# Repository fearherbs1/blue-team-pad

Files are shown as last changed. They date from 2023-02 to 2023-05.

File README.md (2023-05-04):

# blue-team-pad
An open source macropad for the cyber security analyst.

View the documentation for the Blue Team Pad by visiting: https://fearherbs1.github.io/blue-team-pad-docs/

Below is the demo unit that was shown at Champlain's 2023 ITS Capstone Showcase 
blue_team_pad

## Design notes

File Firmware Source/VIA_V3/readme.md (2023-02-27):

# Blue Team Pad

blue_team_pad

An open source macropad for the cyber security analyst.

The Blue Team Pad is a RP2040 based 4x5 macropad with two rotary encoders and OLED display.

It was specifically designed with the maximum possible space for macros supported by QMK. This allows the analyst to store various triage & remediation commands for quick access.

* Keyboard Maintainer: [Thomas Autiello Jr](https://github.com/fearherbs1)
* Hardware Supported: Custom RP2040 Based PCB
* Hardware Availability: https://github.com/fearherbs1/blue-team-pad 

Make example for this keyboard (after setting up your build environment):

    make fearherbs1/blue_team_pad:default

Flashing example for this keyboard:

    make fearherbs1/blue_team_pad:default:flash

See the [build environment setup](https://docs.qmk.fm/#/getting_started_build_tools) and the [make instructions](https://docs.qmk.fm/#/getting_started_make_guide) for more information. Brand new to QMK? Start with our [Complete Newbs Guide](https://docs.qmk.fm/#/newbs).

## Bootloader

Enter the bootloader in 2 ways:

* **Bootmagic reset**: Hold down the upper left encoder and plug in the keyboard
* **Physical reset button**: Briefly short the two "BOOT" pads on the back side of the pcb

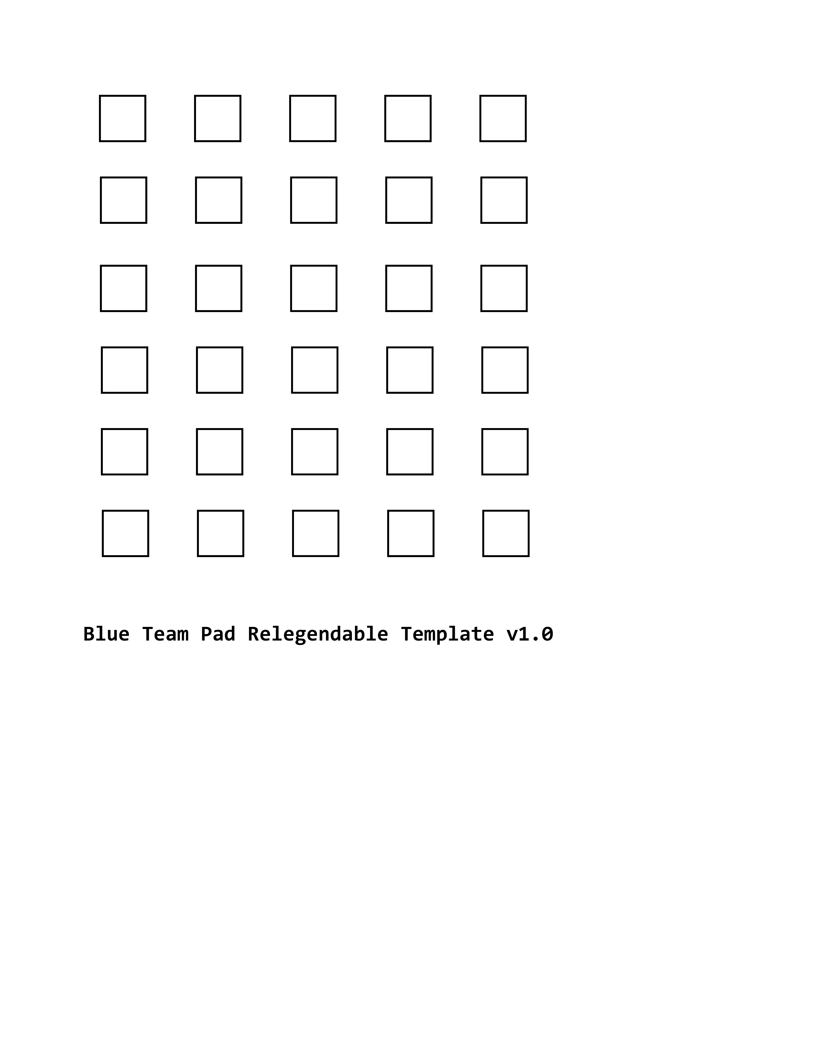
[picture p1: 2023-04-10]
Relegendable Template/BTP relegendable Template V1.png

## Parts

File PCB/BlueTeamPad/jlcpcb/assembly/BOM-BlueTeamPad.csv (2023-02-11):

Comment | Designator | Footprint | LCSC
1k | R5,R6 | R_0402_1005Metric | C11702
100nF | C11,C12,C13,C14,C15,C16,C17,C5,C7,C8 | C_0402_1005Metric | C1525
10uF | C9 | C_0402_1005Metric | C15525
22pF | C3,C4 | C_0402_1005Metric | C1555
USB_C | J1 | USB_C_Receptacle_HRO_TYPE-C-31-M-12 | C165948
RP2040 | U1 | RP2040-QFN-56 | C2040
27R | R1,R2 | R_0603_1608Metric | C25190
10k | R7 | R_0402_1005Metric | C25744
5.1k | R3,R4 | R_0402_1005Metric | C25905
1uF | C1,C10,C2,C6 | C_0402_1005Metric | C52923
XC6206 | U4 | SOT-23 | C5446
500mA | F1 | Fuse_1206_3216Metric | C70076
D_Small | D1,D10,D11,D12,D13,D14,D15,D16,D17,D18,D19,D2,D20,D21,D22,D3,D4,D5,D6,D7,D8,D9 | D_SOD-123 | C81598
SRV05-4 | U2 | SOT-23-6-routable | C85364
12MHz | Y1 | Crystal_SMD_3225-4Pin_3.2x2.5mm | C9002
W25Q128JVS | U3 | SOIC-8_5.23x5.23mm_P1.27mm | C97521
MountingHole_Pad | H2 | MountingHole_2.2mm_M2_Pad
OLED | OL1 | OLED_v2
MountingHole_Pad | H1 | MountingHole_2.2mm_M2_Pad
RotaryEncoder_Switch | SW3 | ROT_Alps_EC11E-Switch
MountingHole_Pad | H3 | MountingHole_2.2mm_M2_Pad
MountingHole_Pad | H4 | MountingHole_2.2mm_M2_Pad
RotaryEncoder_Switch | SW2 | ROT_Alps_EC11E-Switch
MX_SW_HS | SW20 | SW_MX_HS_1u
MX_SW_HS | SW5 | SW_MX_HS_1u
Boot | SW1 | PinSocket_1x02_P2.54mm_Vertical
MX_SW_HS | SW6 | SW_MX_HS_1u
MX_SW_HS | SW21 | SW_MX_HS_1u
MX_SW_HS | SW22 | SW_MX_HS_1u
MX_SW_HS | SW13 | SW_MX_HS_1u
MX_SW_HS | SW18 | SW_MX_HS_1u
MX_SW_HS | SW16 | SW_MX_HS_1u
MX_SW_HS | SW11 | SW_MX_HS_1u
MX_SW_HS | SW12 | SW_MX_HS_1u
MX_SW_HS | SW9 | SW_MX_HS_1u
MX_SW_HS | SW10 | SW_MX_HS_1u
MX_SW_HS | SW7 | SW_MX_HS_1u
MX_SW_HS | SW15 | SW_MX_HS_1u
MX_SW_HS | SW4 | SW_MX_HS_1u
MX_SW_HS | SW8 | SW_MX_HS_1u
MX_SW_HS | SW23 | SW_MX_HS_1u
MX_SW_HS | SW19 | SW_MX_HS_1u
MX_SW_HS | SW14 | SW_MX_HS_1u
MX_SW_HS | SW17 | SW_MX_HS_1u

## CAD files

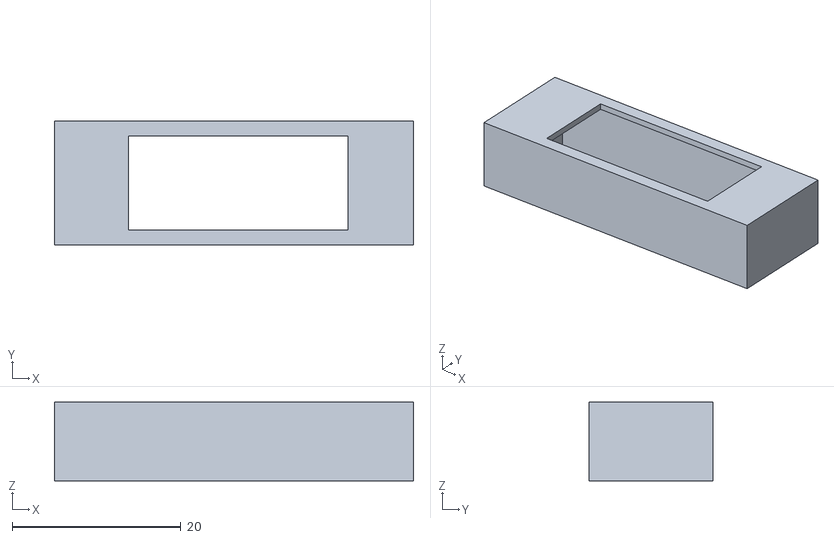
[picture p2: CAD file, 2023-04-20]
Case/STLs/oled_cover_oled_socket.stl
42.5 x 14.6 x 9.30

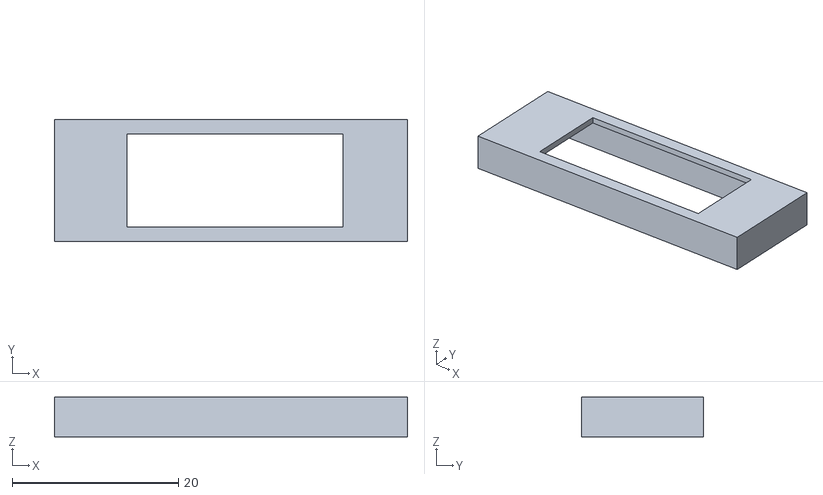
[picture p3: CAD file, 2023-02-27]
Case/STLs/oled cover.stl
42.5 x 14.6 x 4.80

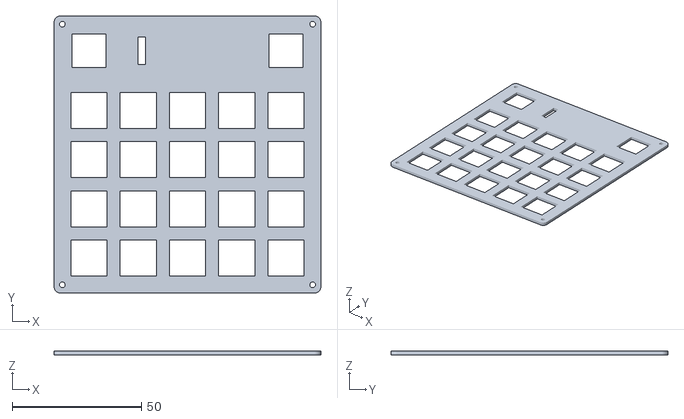
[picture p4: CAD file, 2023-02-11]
Case/STLs/plate.stl
103.2 x 107.2 x 1.60

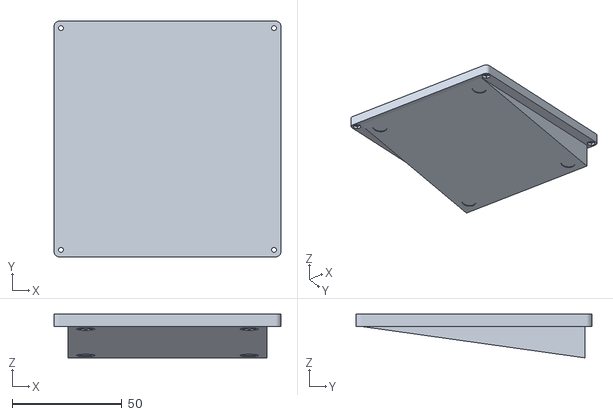
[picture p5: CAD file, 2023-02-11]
Case/STLs/bottom piece.stl
103.2 x 107.2 x 19.9

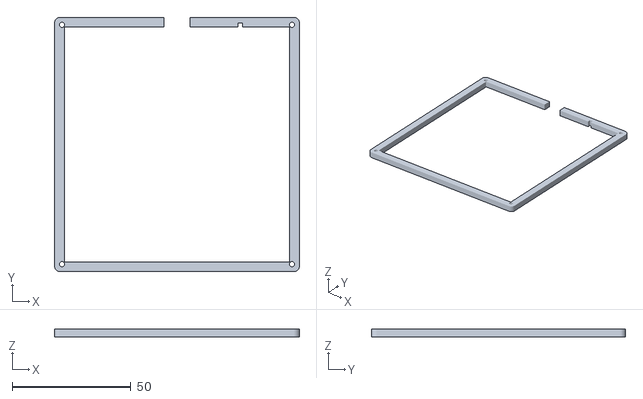
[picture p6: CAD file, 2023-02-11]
Case/STLs/mid peice_usb.stl
103.2 x 107.2 x 3.40

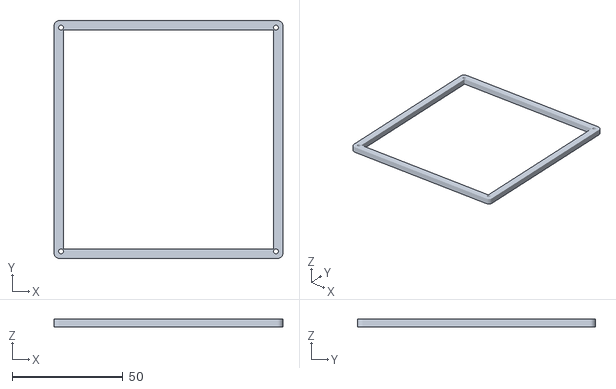
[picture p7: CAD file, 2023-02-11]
Case/STLs/mid peice_plate.stl
103.2 x 107.2 x 3.40

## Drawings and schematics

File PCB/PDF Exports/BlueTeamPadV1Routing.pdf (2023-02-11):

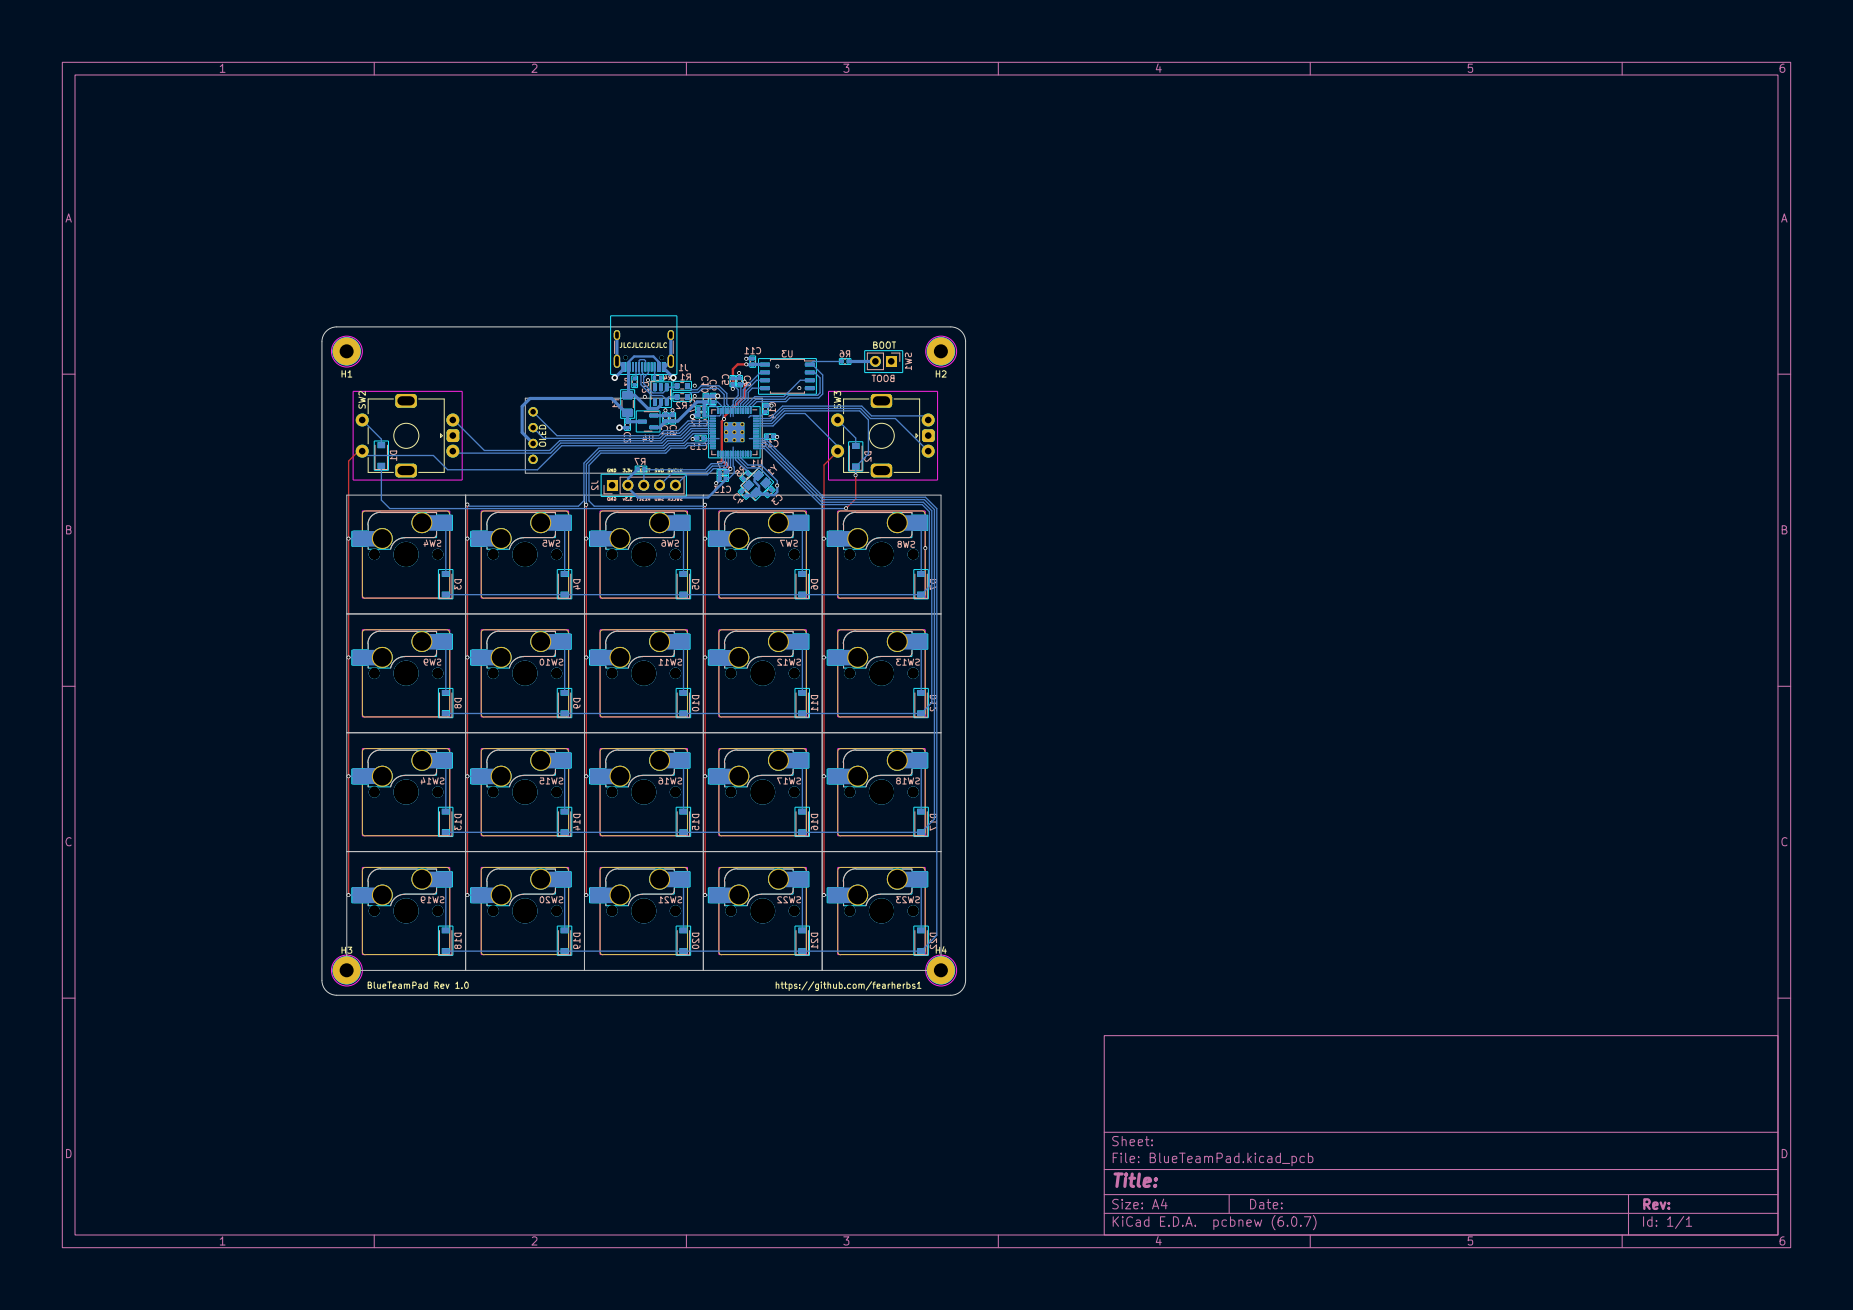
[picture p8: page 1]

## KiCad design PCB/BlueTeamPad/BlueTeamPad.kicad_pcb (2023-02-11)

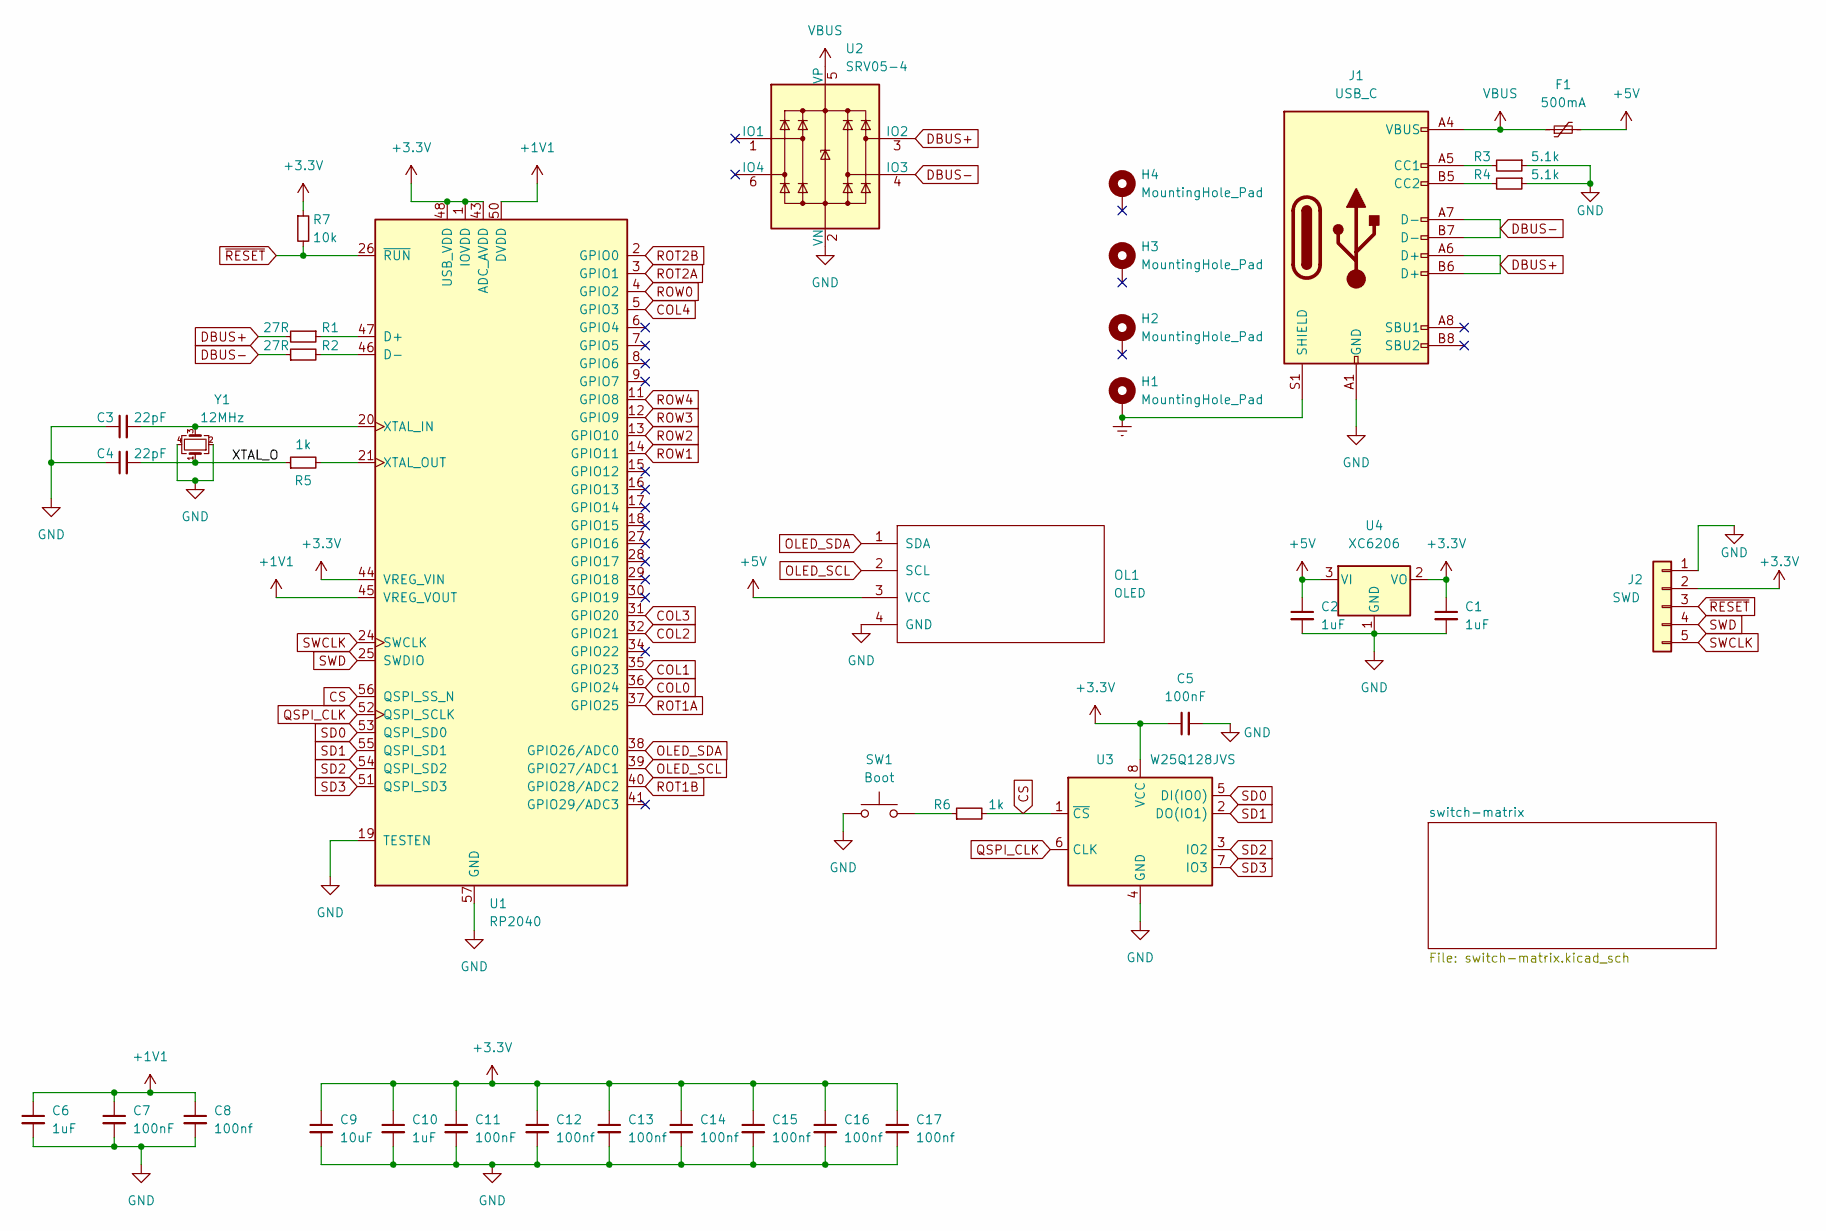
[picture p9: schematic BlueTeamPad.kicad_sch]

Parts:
C1, C2, C10: 1uF; C_0402_1005Metric; LCSC C52923
C3, C4: 22pF; C_0402_1005Metric; LCSC C1555
C5, C7, C11: 100nF; C_0402_1005Metric; LCSC C1525
C6: 1uF; C_0402_1005Metric
C8, C12, C13, C14, C15, C16, C17: 100nf; C_0402_1005Metric; LCSC C1525
C9: 10uF; C_0402_1005Metric; LCSC C15525
F1: 500mA; Fuse_1206_3216Metric; LCSC C70076
H1, H2, H3, H4: MountingHole_Pad; MountingHole_2.2mm_M2_Pad
J1: USB_C; USB_C_Receptacle_HRO_TYPE-C-31-M-12
J2: SWD; PinSocket_1x05_P2.54mm_Vertical
OL1: OLED; OLED_v2
R1, R2: 27R; R_0603_1608Metric; LCSC C25190
R3, R4: 5.1k; R_0402_1005Metric; LCSC C25905
R5, R6: 1k; R_0402_1005Metric; LCSC C11702
R7: 10k; R_0402_1005Metric; LCSC C25744
SW1: Boot; PinSocket_1x02_P2.54mm_Vertical
U1: RP2040; RP2040-QFN-56
U2: SRV05-4; SOT-23-6-routable; LCSC C85364
U3: W25Q128JVS; SOIC-8_5.23x5.23mm_P1.27mm; LCSC C97521
U4: XC6206; SOT-23; LCSC C5446
Y1: 12MHz; Crystal_SMD_3225-4Pin_3.2x2.5mm; LCSC C9002

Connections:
+1V1: C6.1, C7.1, C8.1, U1.23 (DVDD), U1.45 (VREG_VOUT), U1.50 (DVDD)
+3.3V: C1.1, C5.1, C9.1, C10.1, C11.1, C12.1, C13.1, C14.1, C15.1, C16.1, C17.1, J2.2, R7.1, U1.1 (IOVDD), U1.10 (IOVDD), U1.22 (IOVDD), U1.33 (IOVDD), U1.42 (IOVDD), U1.43 (ADC_AVDD), U1.44 (VREG_VIN), U1.48 (USB_VDD), U1.49 (IOVDD), U3.8 (VCC), U4.2 (VO)
+5V: C2.1, F1.2, OL1.3 (VCC), U4.3 (VI)
/XTAL_O: C4.2, R5.1, Y1.1
COL0: U1.36 (GPIO24); also elsewhere on the board
COL1: U1.35 (GPIO23); also elsewhere on the board
COL2: U1.32 (GPIO21); also elsewhere on the board
COL3: U1.31 (GPIO20); also elsewhere on the board
COL4: U1.5 (GPIO3); also elsewhere on the board
CS: R6.2, U1.56 (QSPI_SS_N), U3.1 (~CS)
DBUS+: J1.A6 (D+), J1.B6 (D+), R1.2, U2.3 (IO2)
DBUS-: J1.A7 (D-), J1.B7 (D-), R2.1, U2.4 (IO3)
Earth: H1.1, J1.S1 (SHIELD)
GND: C1.2, C2.2, C3.1, C4.1, C5.2, C6.2, C7.2, C8.2, C9.2, C10.2, C11.2, C12.2, C13.2, C14.2, C15.2, C16.2, C17.2, J1.A1 (GND), J1.A12 (GND), J1.B1 (GND), J1.B12 (GND), J2.1, OL1.4 (GND), R3.1, R4.1, SW1.1, U1.19 (TESTEN), U1.57 (GND), U2.2 (VN), U3.4 (GND), U4.1 (GND), Y1.2, Y1.4; also elsewhere on the board
unnamed: C3.2, U1.20 (XTAL_IN), Y1.3
unnamed: J1.A5 (CC1), R3.2
unnamed: J1.B5 (CC2), R4.2
unnamed: R1.1, U1.47 (D+)
unnamed: R2.2, U1.46 (D-)
unnamed: R5.2, U1.21 (XTAL_OUT)
unnamed: R6.1, SW1.2
OLED_SCL: OL1.2 (SCL), U1.39 (GPIO27/ADC1)
OLED_SDA: OL1.1 (SDA), U1.38 (GPIO26/ADC0)
QSPI_CLK: U1.52 (QSPI_SCLK), U3.6 (CLK)
ROT1A: U1.37 (GPIO25); also elsewhere on the board
ROT1B: U1.40 (GPIO28/ADC2); also elsewhere on the board
ROT2A: U1.3 (GPIO1); also elsewhere on the board
ROT2B: U1.2 (GPIO0); also elsewhere on the board
ROW0: U1.4 (GPIO2); also elsewhere on the board
ROW1: U1.14 (GPIO11); also elsewhere on the board
ROW2: U1.13 (GPIO10); also elsewhere on the board
ROW3: U1.12 (GPIO9); also elsewhere on the board
ROW4: U1.11 (GPIO8); also elsewhere on the board
SD0: U1.53 (QSPI_SD0), U3.5 (DI(IO0))
SD1: U1.55 (QSPI_SD1), U3.2 (DO(IO1))
SD2: U1.54 (QSPI_SD2), U3.3 (IO2)
SD3: U1.51 (QSPI_SD3), U3.7 (IO3)
SWCLK: J2.5, U1.24 (SWCLK)
SWD: J2.4, U1.25 (SWDIO)
VBUS: F1.1, J1.A4 (VBUS), J1.A9 (VBUS), J1.B4 (VBUS), J1.B9 (VBUS), U2.5 (VP)
~RESET: J2.3, R7.2, U1.26 (~RUN)

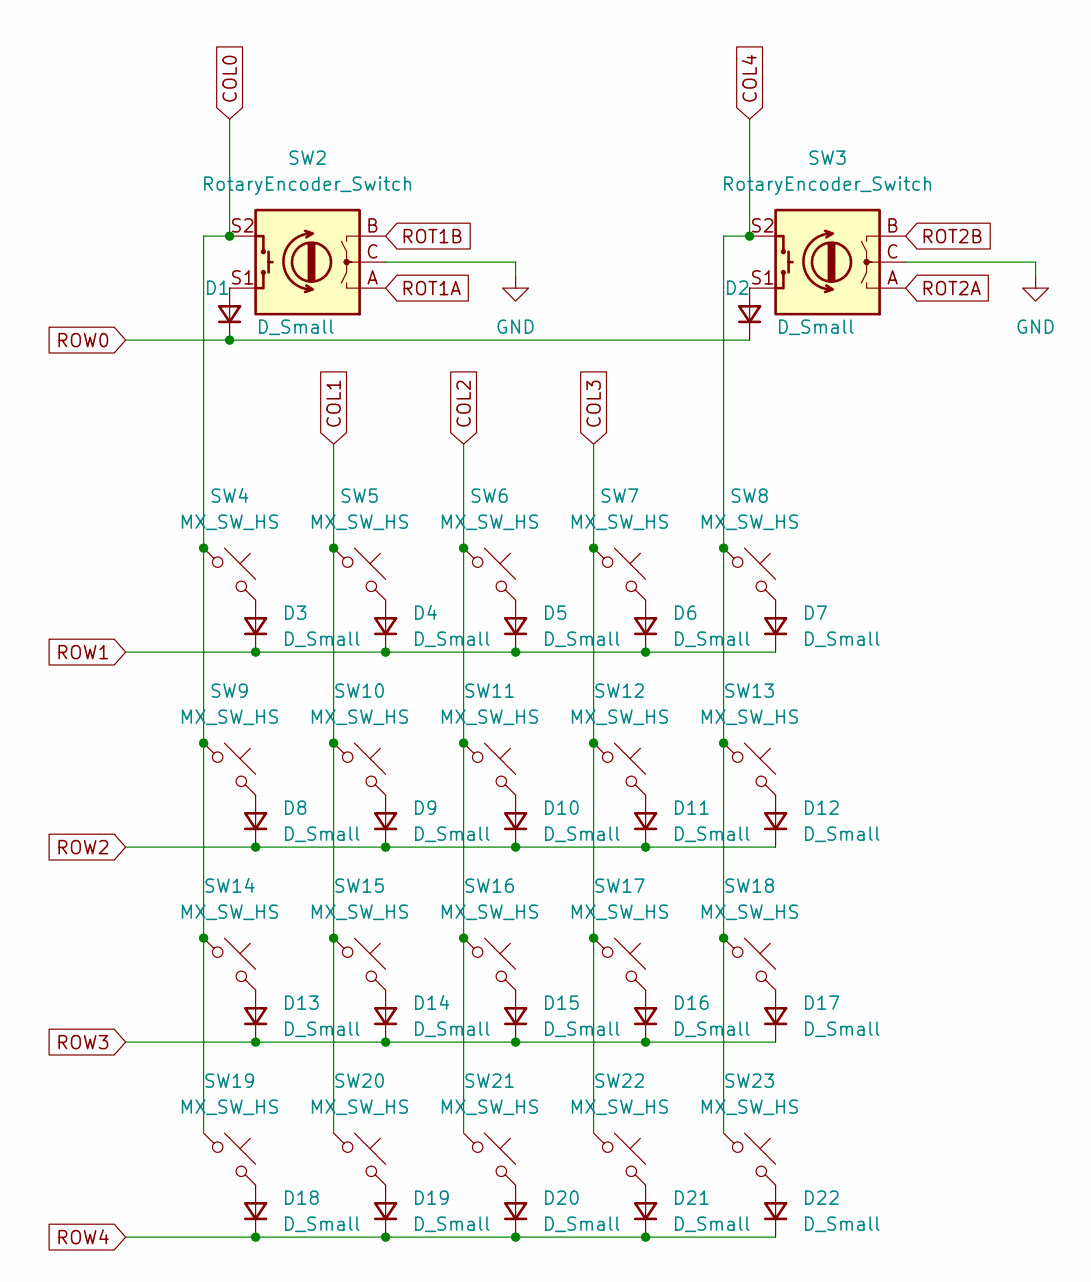
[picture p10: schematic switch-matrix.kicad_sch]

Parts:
D1, D2, D3, D4, D5, D6, D7, D8, D9, D10, D11, D12, D13, D14, D15, D16, D17, D18, D19, D20, D21, D22: D_Small; D_SOD-123; LCSC C81598
SW2, SW3: RotaryEncoder_Switch; ROT_Alps_EC11E-Switch
SW4, SW5, SW6, SW7, SW8, SW9, SW10, SW11, SW12, SW13, SW14, SW15, SW16, SW17, SW18, SW19, SW20, SW21, SW22, SW23: MX_SW_HS; SW_MX_HS_1u

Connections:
COL0: SW2.S2, SW4.1, SW9.1, SW14.1, SW19.1; also elsewhere on the board
COL1: SW5.1, SW10.1, SW15.1, SW20.1; also elsewhere on the board
COL2: SW6.1, SW11.1, SW16.1, SW21.1; also elsewhere on the board
COL3: SW7.1, SW12.1, SW17.1, SW22.1; also elsewhere on the board
COL4: SW3.S2, SW8.1, SW13.1, SW18.1, SW23.1; also elsewhere on the board
GND: SW2.C, SW3.C; also elsewhere on the board
unnamed: D1.2 (A), SW2.S1
unnamed: D2.2 (A), SW3.S1
unnamed: D3.2 (A), SW4.2
unnamed: D4.2 (A), SW5.2
unnamed: D5.2 (A), SW6.2
unnamed: D6.2 (A), SW7.2
unnamed: D7.2 (A), SW8.2
unnamed: D8.2 (A), SW9.2
unnamed: D9.2 (A), SW10.2
unnamed: D10.2 (A), SW11.2
unnamed: D11.2 (A), SW12.2
unnamed: D12.2 (A), SW13.2
unnamed: D13.2 (A), SW14.2
unnamed: D14.2 (A), SW15.2
unnamed: D15.2 (A), SW16.2
unnamed: D16.2 (A), SW17.2
unnamed: D17.2 (A), SW18.2
unnamed: D18.2 (A), SW19.2
unnamed: D19.2 (A), SW20.2
unnamed: D20.2 (A), SW21.2
unnamed: D21.2 (A), SW22.2
unnamed: D22.2 (A), SW23.2
ROT1A: SW2.A; also elsewhere on the board
ROT1B: SW2.B; also elsewhere on the board
ROT2A: SW3.A; also elsewhere on the board
ROT2B: SW3.B; also elsewhere on the board
ROW0: D1.1 (K), D2.1 (K); also elsewhere on the board
ROW1: D3.1 (K), D4.1 (K), D5.1 (K), D6.1 (K), D7.1 (K); also elsewhere on the board
ROW2: D8.1 (K), D9.1 (K), D10.1 (K), D11.1 (K), D12.1 (K); also elsewhere on the board
ROW3: D13.1 (K), D14.1 (K), D15.1 (K), D16.1 (K), D17.1 (K); also elsewhere on the board
ROW4: D18.1 (K), D19.1 (K), D20.1 (K), D21.1 (K), D22.1 (K); also elsewhere on the board

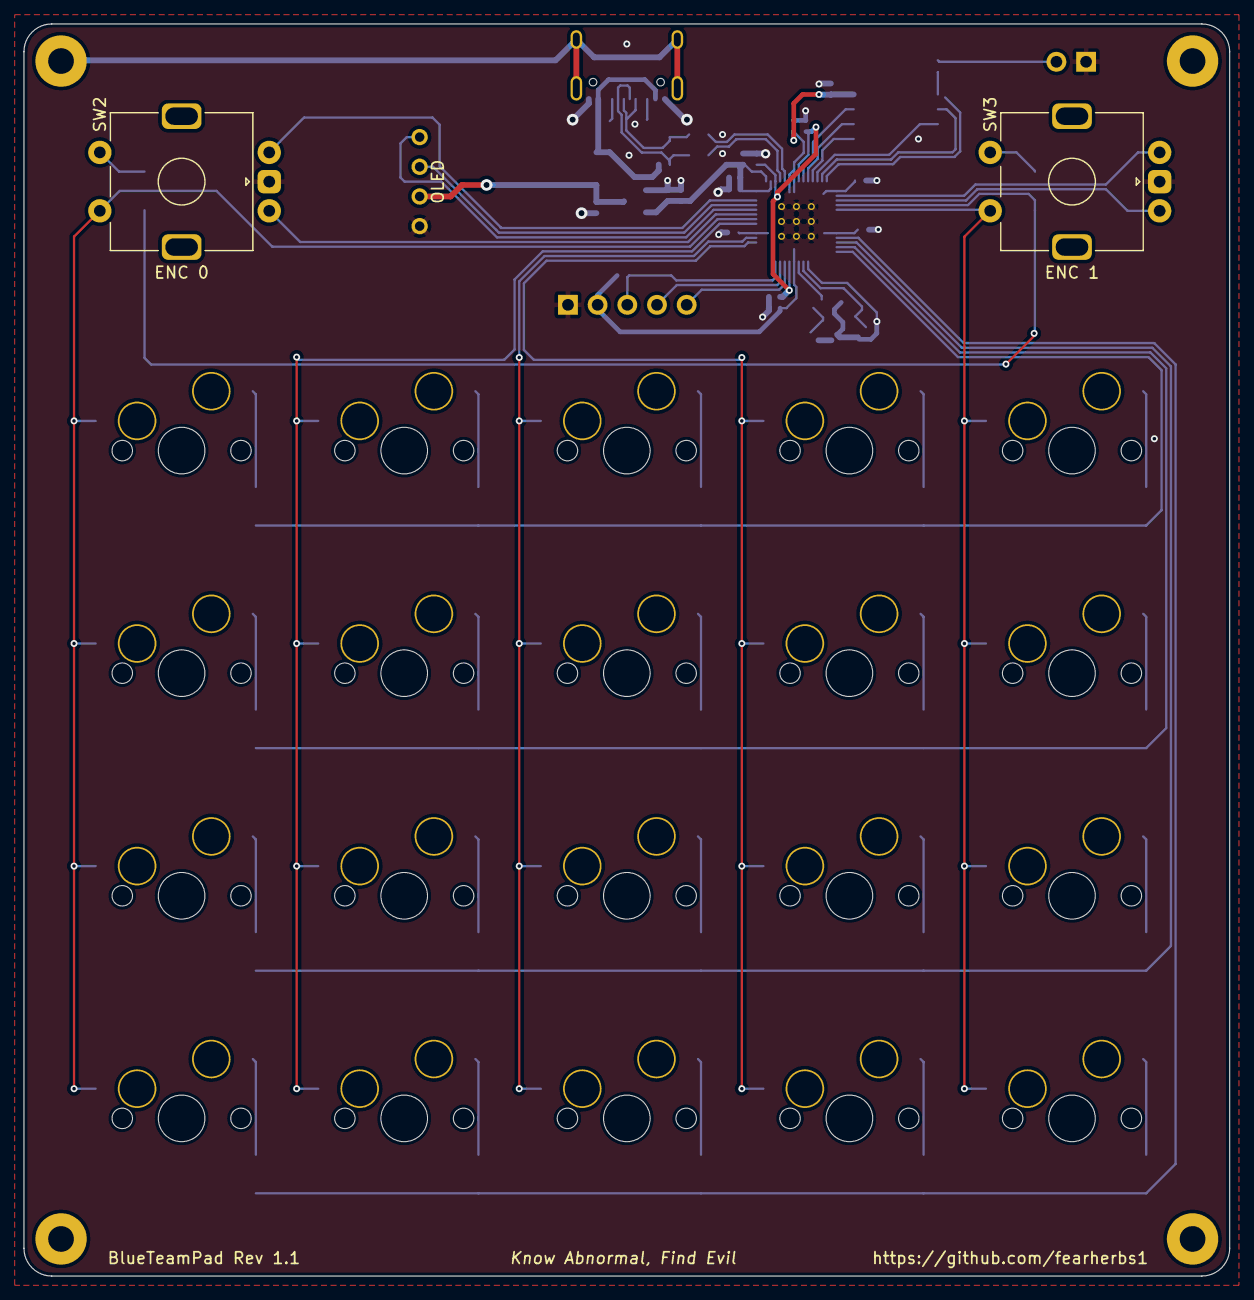
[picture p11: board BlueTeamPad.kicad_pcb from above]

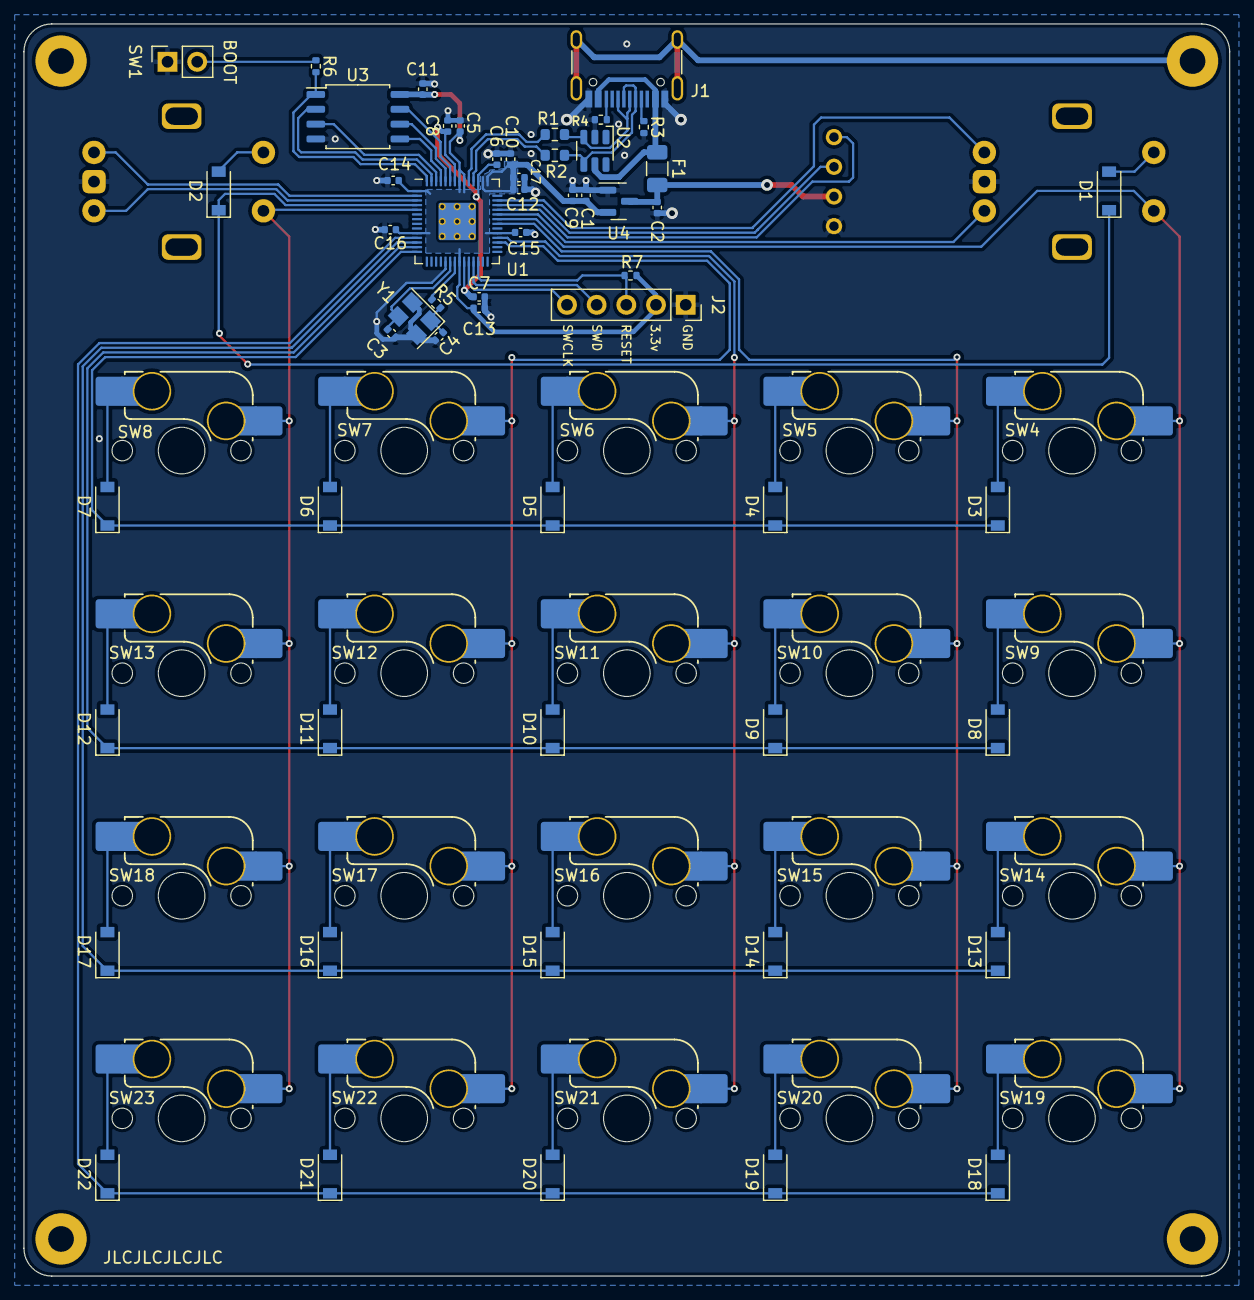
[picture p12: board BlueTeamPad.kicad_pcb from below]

Board: 2 copper layers, 103.2 x 107.2 mm, 82 parts (75 on the bottom side), 63 nets.

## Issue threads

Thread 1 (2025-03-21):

PolySprint

Wyvest, 2025-03-21:
Hi,

Sorry for the unrelated issue but I am unsure where else to contact you.

I am trying to "leave the fork network" and turn PolySprint into a standalone repo. However, I cannot as there are currently 3 child forks, including yours. Could you temporarily delete the repo and let me know when you do, so I can do this?

Thanks in advance

fearherbs1, 2025-03-22:
Hey @Wyvest, no worries, I went ahead and detached my PolySprint fork from the main PolySprint Repo, so it should not prevent you from "leaving the fork network" on your end.

Closed 2025-03-22.

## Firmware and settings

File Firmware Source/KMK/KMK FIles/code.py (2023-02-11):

print("Starting")

import board

from kmk.kmk_keyboard import KMKKeyboard
from kmk.consts import UnicodeMode
from kmk.keys import KC
from kmk.scanners import DiodeOrientation
from kmk.modules.layers import Layers
from kmk.modules.encoder import EncoderHandler
from kmk.extensions.media_keys import MediaKeys
from kmk.handlers.sequences import send_string

keyboard = KMKKeyboard()
layers = Layers()
encoder_handler = EncoderHandler()
keyboard.modules = [layers, encoder_handler]

encoder_handler.pins = ((board.GP25, board.GP28, None, False), (board.GP1, board.GP0, None, False),)
keyboard.col_pins = (board.GP24, board.GP23, board.GP21, board.GP20, board.GP3)
keyboard.row_pins = (board.GP2, board.GP11, board.GP10, board.GP9, board.GP8)
keyboard.diode_orientation = DiodeOrientation.COL2ROW

keyboard.extensions.append(MediaKeys())

encoder_handler.map = ( ((KC.AUDIO_VOL_UP, KC.AUDIO_VOL_DOWN, KC.NO),( KC.MEDIA_NEXT_TRACK, KC.MEDIA_PREV_TRACK,KC.NO),),
                        ((KC.AUDIO_VOL_UP, KC.AUDIO_VOL_DOWN, KC.NO),( KC.MEDIA_NEXT_TRACK, KC.MEDIA_PREV_TRACK,KC.NO),),
                        ((KC.AUDIO_VOL_UP, KC.AUDIO_VOL_DOWN, KC.NO),( KC.MEDIA_NEXT_TRACK, KC.MEDIA_PREV_TRACK,KC.NO),),
                        )

keyboard.debug_enabled = False

M1 = send_string("gci \"C:\\Users\\*\\AppData\\Roaming\\Microsoft\\Windows\\Start Menu\\Programs\\Startup\\*\"")

keyboard.keymap = [
    [
    KC.AUDIO_MUTE, KC.NO,KC.NO, KC.NO, KC.MEDIA_PLAY_PAUSE, 
	M1, KC.D, KC.E, KC.F, KC.G, 
	KC.H, KC.I, KC.J, KC.K, KC.L, 
	KC.M, KC.N, KC.O, KC.P, KC.Q, 
	KC.R, KC.S, KC.T, KC.U, KC.Z
    ],
    [
    KC.A, KC.NO,KC.NO, KC.NO, KC.C, 
	KC.C, KC.D, KC.E, KC.F, KC.G, 
	KC.H, KC.I, KC.J, KC.K, KC.L, 
	KC.M, KC.N, KC.O, KC.P, KC.Q, 
	KC.R, KC.S, KC.T, KC.U, KC.Z
    ],
    [
    KC.A, KC.NO,KC.NO, KC.NO, KC.C, 
	KC.C, KC.D, KC.E, KC.F, KC.G, 
	KC.H, KC.I, KC.J, KC.K, KC.L, 
	KC.M, KC.N, KC.O, KC.P, KC.Q, 
	KC.R, KC.S, KC.T, KC.U, KC.Z
    ]
]

if __name__ == '__main__':
    keyboard.go()

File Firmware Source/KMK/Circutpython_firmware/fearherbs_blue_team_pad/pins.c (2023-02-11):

#include "shared-bindings/board/__init__.h"

STATIC const mp_rom_map_elem_t board_module_globals_table[] = {
    CIRCUITPYTHON_BOARD_DICT_STANDARD_ITEMS

    { MP_ROM_QSTR(MP_QSTR_GP0), MP_ROM_PTR(&pin_GPIO0) },
    { MP_ROM_QSTR(MP_QSTR_GP1), MP_ROM_PTR(&pin_GPIO1) },
    { MP_ROM_QSTR(MP_QSTR_GP2), MP_ROM_PTR(&pin_GPIO2) },
    { MP_ROM_QSTR(MP_QSTR_GP3), MP_ROM_PTR(&pin_GPIO3) },
    { MP_ROM_QSTR(MP_QSTR_GP4), MP_ROM_PTR(&pin_GPIO4) },
    { MP_ROM_QSTR(MP_QSTR_GP5), MP_ROM_PTR(&pin_GPIO5) },
    { MP_ROM_QSTR(MP_QSTR_GP6), MP_ROM_PTR(&pin_GPIO6) },
    { MP_ROM_QSTR(MP_QSTR_GP7), MP_ROM_PTR(&pin_GPIO7) },
    { MP_ROM_QSTR(MP_QSTR_GP8), MP_ROM_PTR(&pin_GPIO8) },
    { MP_ROM_QSTR(MP_QSTR_GP9), MP_ROM_PTR(&pin_GPIO9) },
    { MP_ROM_QSTR(MP_QSTR_GP10), MP_ROM_PTR(&pin_GPIO10) },
    { MP_ROM_QSTR(MP_QSTR_GP11), MP_ROM_PTR(&pin_GPIO11) },
    { MP_ROM_QSTR(MP_QSTR_GP12), MP_ROM_PTR(&pin_GPIO12) },
    { MP_ROM_QSTR(MP_QSTR_GP13), MP_ROM_PTR(&pin_GPIO13) },
    { MP_ROM_QSTR(MP_QSTR_GP14), MP_ROM_PTR(&pin_GPIO14) },
    { MP_ROM_QSTR(MP_QSTR_GP15), MP_ROM_PTR(&pin_GPIO15) },
    { MP_ROM_QSTR(MP_QSTR_GP16), MP_ROM_PTR(&pin_GPIO16) },
    { MP_ROM_QSTR(MP_QSTR_GP17), MP_ROM_PTR(&pin_GPIO17) },
    { MP_ROM_QSTR(MP_QSTR_GP18), MP_ROM_PTR(&pin_GPIO18) },
    { MP_ROM_QSTR(MP_QSTR_GP19), MP_ROM_PTR(&pin_GPIO19) },
    { MP_ROM_QSTR(MP_QSTR_GP20), MP_ROM_PTR(&pin_GPIO20) },
    { MP_ROM_QSTR(MP_QSTR_GP21), MP_ROM_PTR(&pin_GPIO21) },
    { MP_ROM_QSTR(MP_QSTR_GP22), MP_ROM_PTR(&pin_GPIO22) },
    { MP_ROM_QSTR(MP_QSTR_GP23), MP_ROM_PTR(&pin_GPIO23) },
    { MP_ROM_QSTR(MP_QSTR_GP24), MP_ROM_PTR(&pin_GPIO24) },
    { MP_ROM_QSTR(MP_QSTR_GP25), MP_ROM_PTR(&pin_GPIO25) },
    { MP_ROM_QSTR(MP_QSTR_GP26), MP_ROM_PTR(&pin_GPIO26) },
    { MP_ROM_QSTR(MP_QSTR_GP27), MP_ROM_PTR(&pin_GPIO27) },
    { MP_ROM_QSTR(MP_QSTR_GP28), MP_ROM_PTR(&pin_GPIO28) },
    { MP_ROM_QSTR(MP_QSTR_GP29), MP_ROM_PTR(&pin_GPIO29) }

};
MP_DEFINE_CONST_DICT(board_module_globals, board_module_globals_table);

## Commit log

2023-02-11 Initial File Add
    [BOM-BlueTeamPad.csv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]
2023-02-27 Update to Current
    [oled cover.stl, plate.stl]
